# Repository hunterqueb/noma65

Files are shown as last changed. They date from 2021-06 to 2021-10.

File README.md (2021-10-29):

# noma65
Open Source 3D Printed 65% Gasket Mounted Keyboard

# File Use
noma65 is licensed under the MIT License.

These files are open and free for you to modify or profit from in any way. Because of my openness for modification, I will not be providing any tutorials for how to use SOLIDWORKS, how to use Autodesk, building the keyboard itself, or placing orders for any materials. I wish for this repo to mearly be a nice framework for anyone already familar with CAD and custom keyboards to freely use these files.

# Images
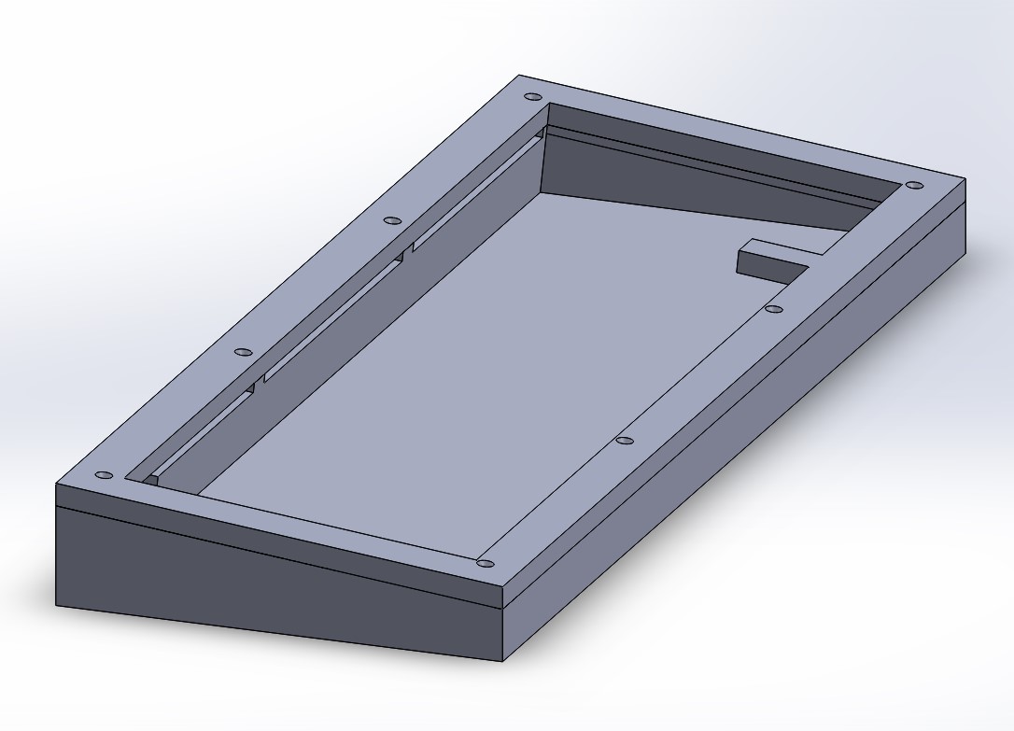
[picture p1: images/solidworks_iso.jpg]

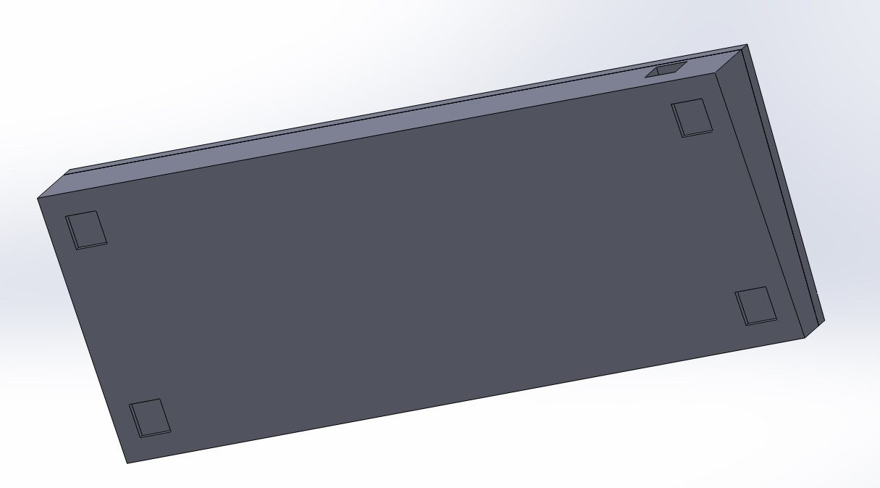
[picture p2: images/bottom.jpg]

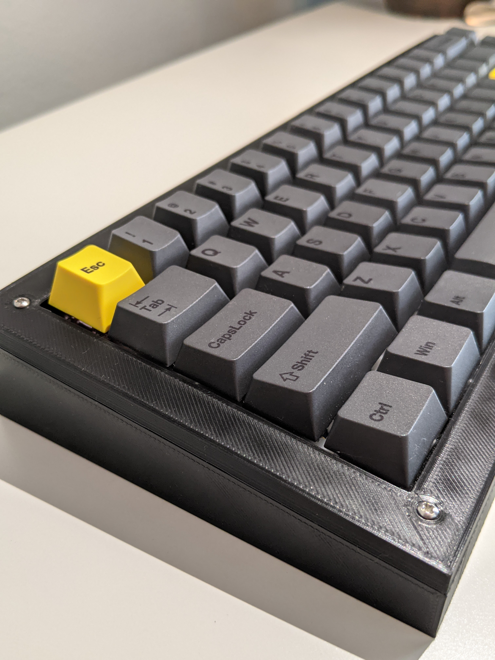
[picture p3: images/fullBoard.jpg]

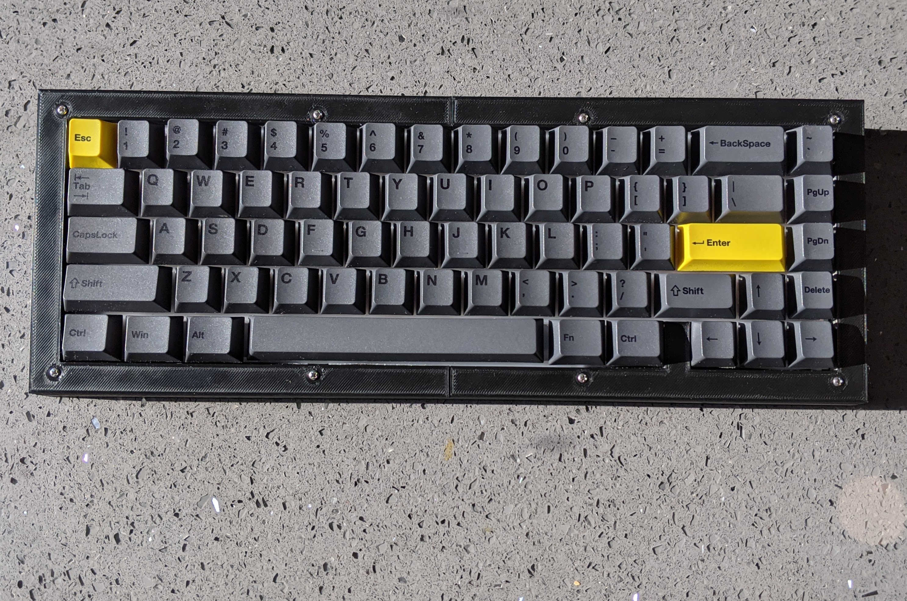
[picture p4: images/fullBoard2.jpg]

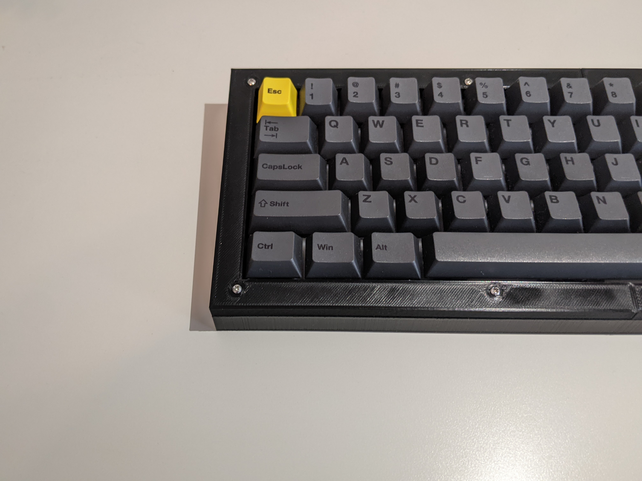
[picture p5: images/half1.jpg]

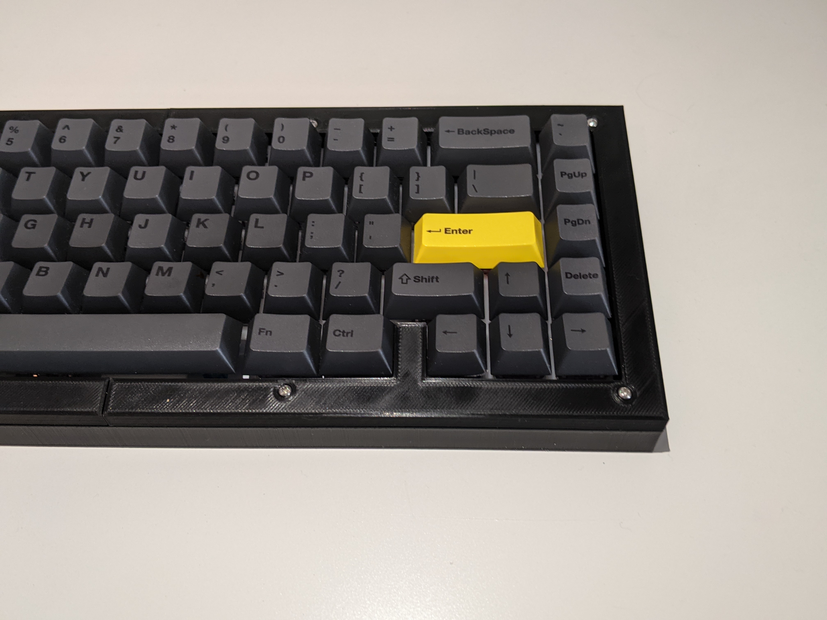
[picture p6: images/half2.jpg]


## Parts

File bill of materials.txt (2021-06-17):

Materials

8 m2x12 screws - https://www.amazon.com/Hilitchi-300-Piece-Phillips-Assortment-stainless/dp/B01NBOD98K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

1/16 in Neoprene Foam Padding for gaskets, cut to size with a razor - https://www.amazon.com/dp/B081PWQK1H?psc=1&ref=ppx_yo2_dt_b_product_details

2mm thick Rubber anti-skid pads cut to size - https://www.amazon.com/gp/product/B01K7JFXAA/ref=ppx_yo_dt_b_asin_title_o06_s00?ie=UTF8&psc=1

3D print Settings

On my CR10 V2, I printed the design by with 15% infill, rafts, and tree supports.

Printed using Black Overture PLA - https://www.amazon.com/gp/product/B01K7JFXAA/ref=ppx_yo_dt_b_asin_title_o06_s00?ie=UTF8&psc=1

Plate Manufacturing

I ordered my design plate on sculptero. I ordered a 2mm POM plate to be laser cut. If you can find a 1.5mm plate, get one so the key switches can clip into place.

If you have a large enough print bed, you can also 3D print one with a material of your choice and the files are included. Note that I have not tested it.

Keyboard Materials

67 Keyswitches with arrowblocker, or 68 keyswitches without arrowblocker

3 2u stabilizers
1 6.25 stabilizer

set of keycaps

65% PCB of an approximate size of 302.5mm x 92.5mm with a USB C port on the left size of the PCB. I used the Instant65 - https://cannonkeys.com/collections/pcbs/products/instant65-pcb?variant=32068070080623

Approximate Cost:
Material Cost: $30
PLA Cost: ~$6.66
Plate Manufacturing Cost: $50

Board cost without keyboard materials: ~$86

Cost I spent on Keyboard materials: 
PCB: $65
Keyswitches: $30
Stablizers: $20
Keycaps: $30

Total board cost that I spent: ~$230

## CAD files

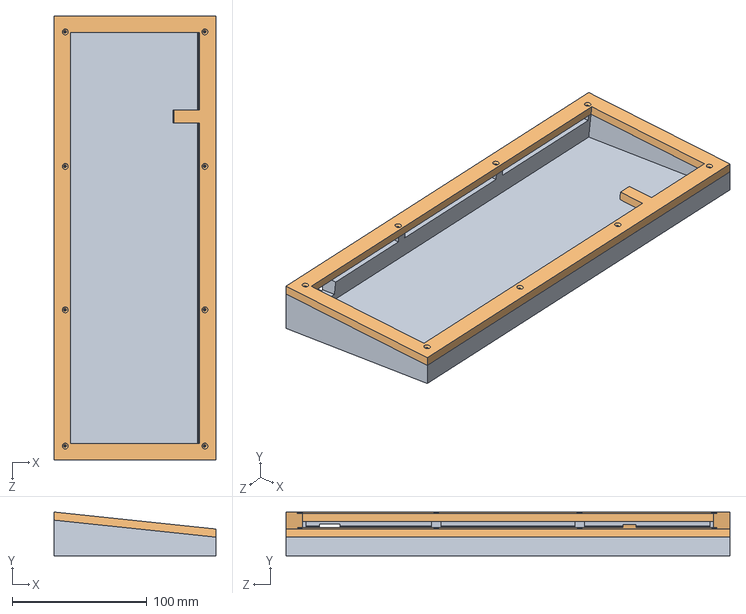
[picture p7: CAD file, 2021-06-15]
solidworks files/keyboard assembly.SLDASM
120.3 x 32.7 x 330.0 mm
bottom
top

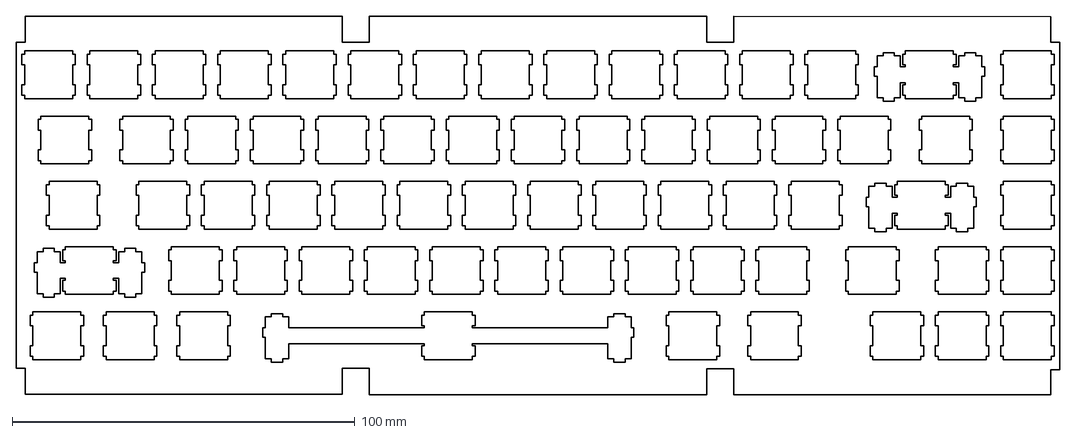
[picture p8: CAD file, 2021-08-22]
plate files/noma-65.dxf
304.8 x 110.4 mm

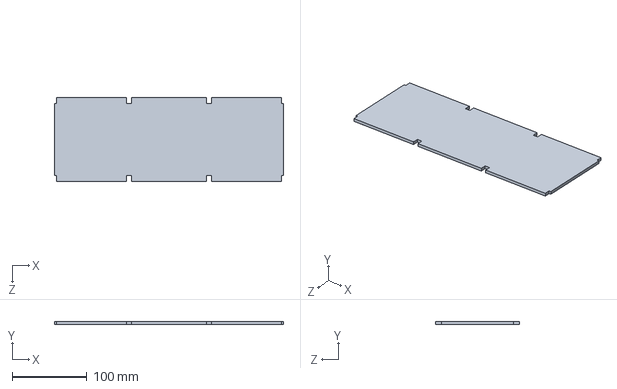
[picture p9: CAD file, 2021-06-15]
solidworks files/just gasket.SLDPRT
305.8 x 3.90 x 112.0 mm

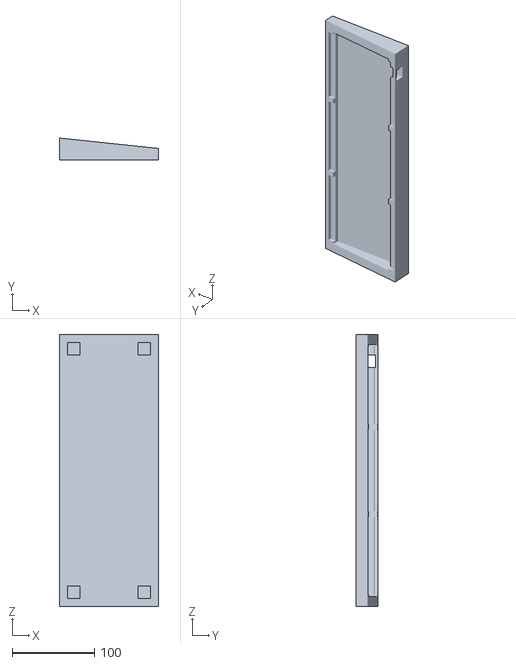
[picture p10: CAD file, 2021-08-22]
stl files/keyboardBody.STL
120.3 x 26.6 x 330.0

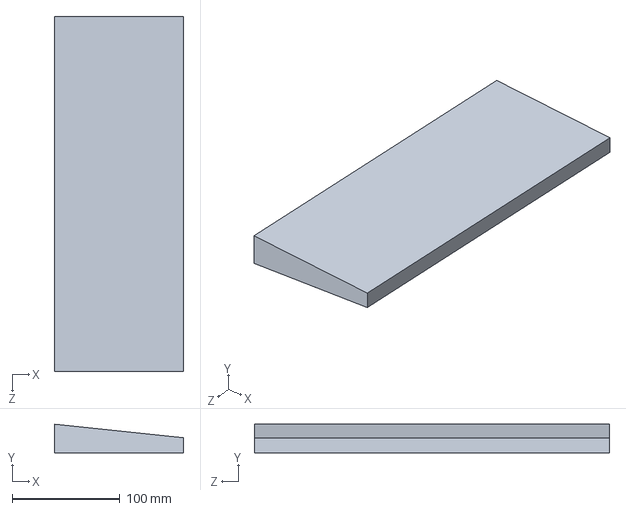
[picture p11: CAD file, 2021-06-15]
solidworks files/bottom.SLDPRT
120.3 x 26.6 x 330.0 mm

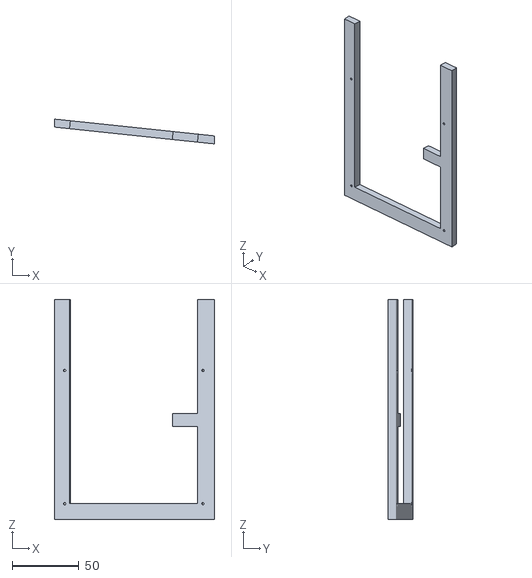
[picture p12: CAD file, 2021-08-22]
stl files/rightTop.STL
120.3 x 18.7 x 165.0

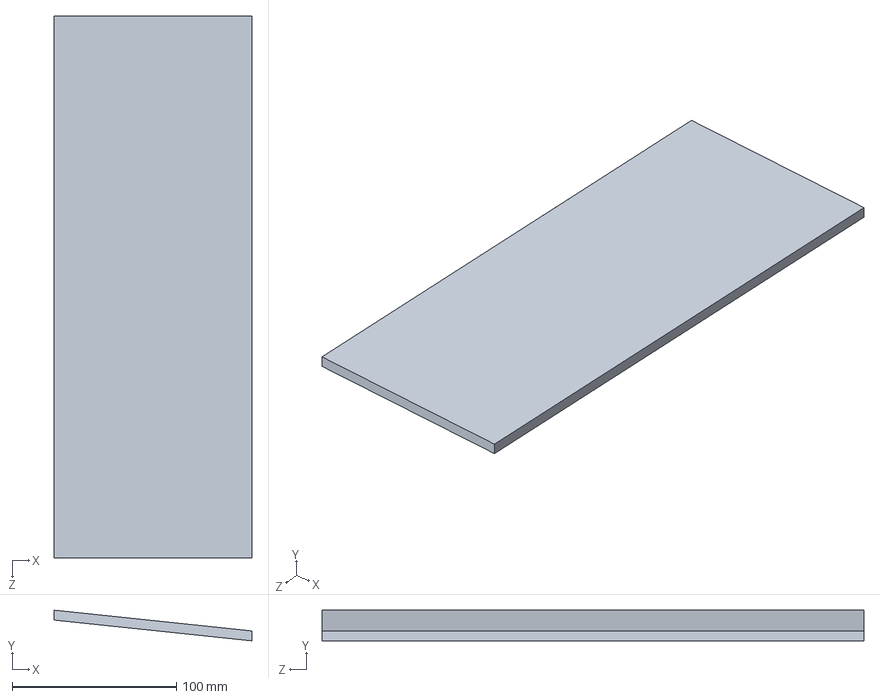
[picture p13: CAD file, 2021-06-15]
solidworks files/top.SLDPRT
120.3 x 18.7 x 330.0 mm

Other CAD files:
stl files/leftTop.STL
plate files/noma-65.dwg

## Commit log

2021-06-15 Added solidworks files
    [bottom.SLDPRT, just gasket.SLDPRT, keyboard assembly.SLDASM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]
2021-06-15 rearranged the solidworks files
    [bottom.SLDPRT, just gasket.SLDPRT, keyboard assembly.SLDASM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]
2021-06-15 added a bill of materials, not finished yet
2021-06-17 added dimension of the pcb
2021-08-22 uploaded plate files
    [noma-65.dwg, noma-65.dxf]
2021-08-22 uploaded print files
    [keyboardBody.STL, leftTop.STL, rightTop.STL]
